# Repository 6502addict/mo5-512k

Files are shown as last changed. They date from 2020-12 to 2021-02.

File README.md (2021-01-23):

# mo5-512k
MO5 512K Cartridge
<br>
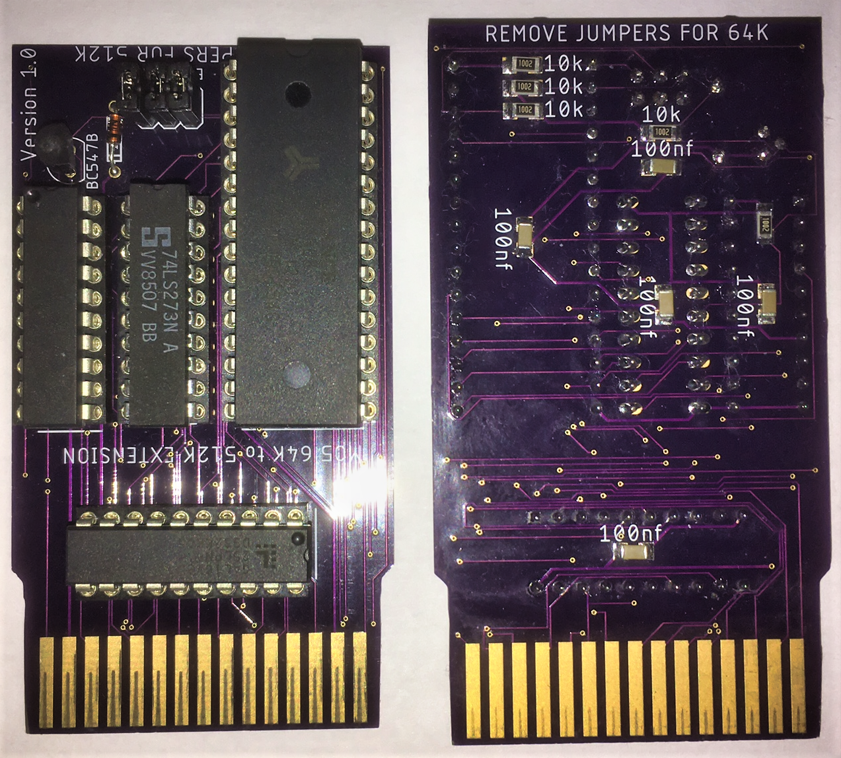
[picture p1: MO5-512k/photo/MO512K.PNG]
al-tag

<br>
## Description
this cartridge is compatible with thomson MO5 64k cartridge
it's not a exact copy of the original cartridge<br>
but rather a rebuild from the manual
<br>
the $A7CB register controlling a MO5 64 cartrige is extended
to permit the access to 512k of memory
<br>
without the 3 jumpers the cartridge is behaving as the 
original thomson MEMO5 cartridge
<br>
with the jumpers set the cartridge can address 512k or memory
<br>

## Note:
The first goal of this board was to replace the original thomson board of 64K
<br>
with the use of modern chips it is easier to find a 128k or 512k chip than 64k
<br>
so I designed the 64k compatibility as the main feature and the extension
<br>
to 128k or 512k (dépending on the ram chip used AS6C1008 or AS6C4008) as goody.
<br>
Due to negative comment on forums saying that this extra memory is useless
<br>
I've listened this comments and removed the jumpers permitting to exploit
<br>
the extra memory.
<br>
As a few 512k board exist I let 512k test procedure and manual
but eagle files are now for 64k boards

## Control Register in $A7CB (without jumpers)
```
bits 0-1   bank number
bit 2      1 = ram visible
           0 = basic
bit 3      1 cartridge ram is readable and writable
           0  cartridge ram is readable and read only
bits 4-7   unused        
```

## Control Register in $A7CB (with jumpers)
```
bits 0-1   bank number
bit 2      1 = ram visible
           0 = basic
bit 3      1 cartridge ram is readable and writable
           0  cartridge ram is readable and read only
bit 4-6    extend the bank number
bit 7      unused
```

## PCB
the pcb can be ordered from oshpark<br>
https://oshpark.com/shared_projects/e0GleW5L

## Bill of Materials
* 1 x socket  dip 32  600mil
* 3 x sockets dip 20  300mil
* 1 74LS273
* 1 RAM Alliance AS6C4008
* 2 GAL Lattice 16v8D
* 1 diode 1N4148
* 5 resistor 10k    1206
* 5 capacitor 100nf 1206
* 1 block of 3 jumpers

## GAL programming
the GALS can be easily programmed with a TL866-II plus programmer<br>
GAL-16V8D-AC7B is going in the horizontal socket  (check the marking)<br>
GAL-16V8D-MO512K is going in the vertical socket

## GAL compiling
The .JED files are sufficent to build the board<br>
they can be recompiled from the .VHD by using:<br>
"Lattice ispLEVER Classic"

## Build of the board
the easiest is to solder the component in the following order<br>
1. 5 100nf capacitor (back of the board)<br>
2. 5 10k resistor (back of the board)<br>
3. 4 sockets<br
4. BC547B<br>
5. 1N4148<br>
6. jumpers<br>

## Test programs
the test program is on Daniel's web site:  http://dcmoto.free.fr/programmes/test512k-mo5/index.html

## Test procedure
follow the instructions in https://github.com/6502addict/mo5-512k/blob/main/MO5-512k/debug

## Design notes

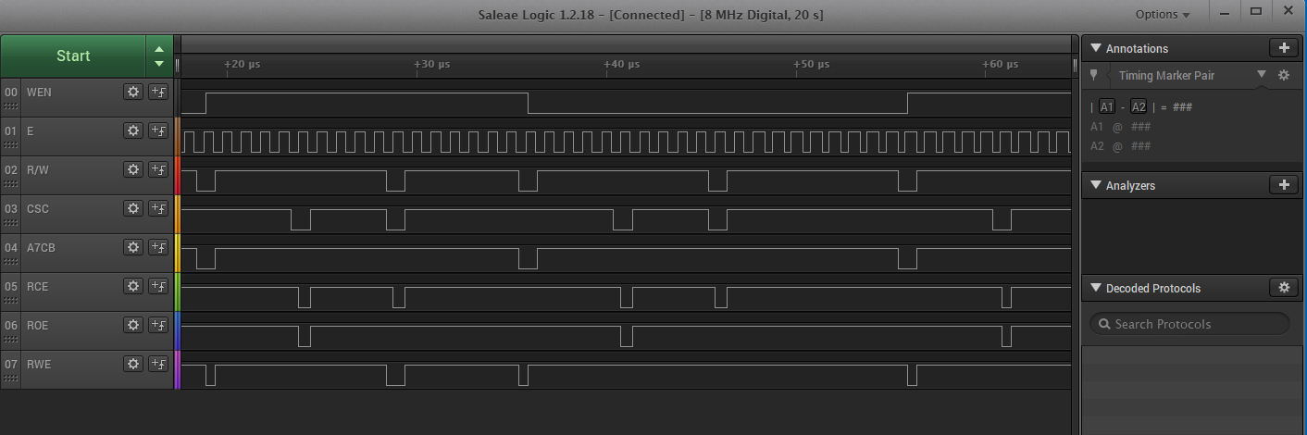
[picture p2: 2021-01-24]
MO5-512k/RAMCTRL.PNG

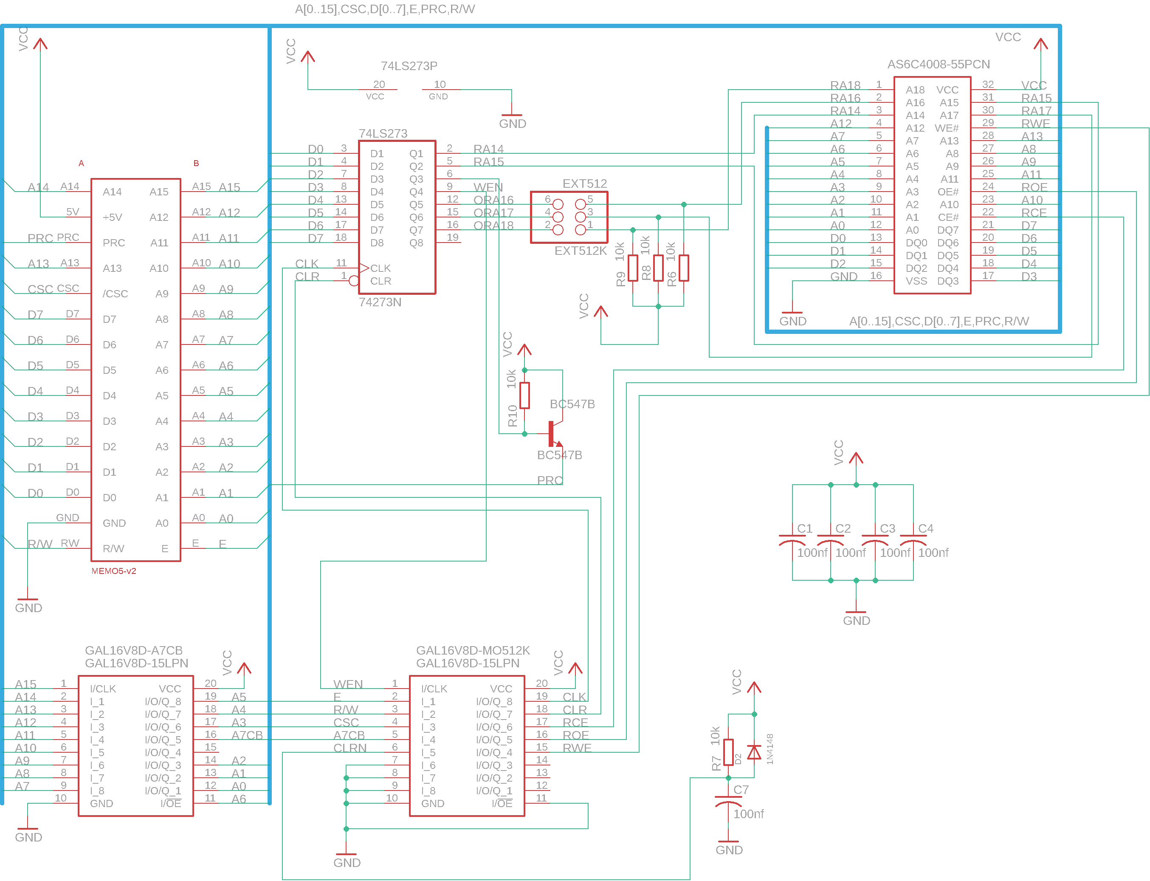
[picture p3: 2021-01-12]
MO5-512k/pcb/mo512k-sch.png

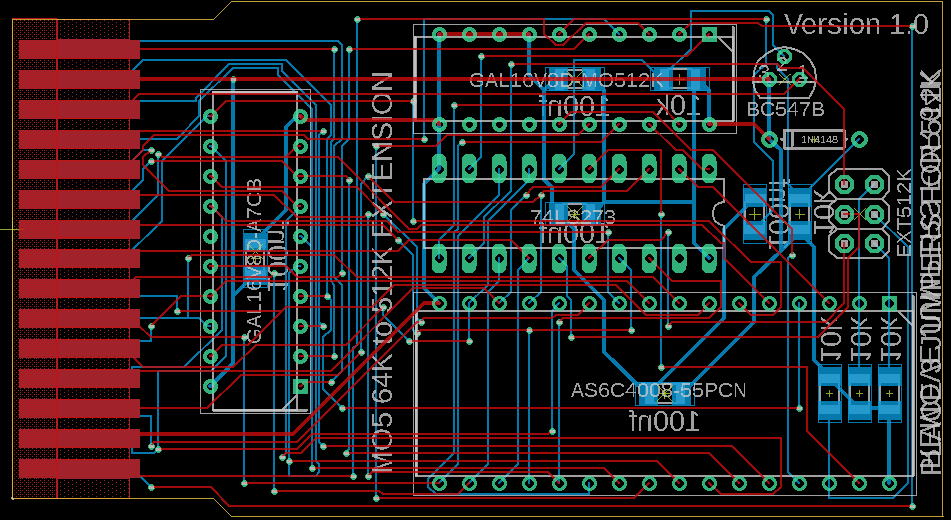
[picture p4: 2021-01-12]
MO5-512k/pcb/mo512k-brd.png

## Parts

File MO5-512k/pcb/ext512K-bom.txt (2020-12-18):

Partlist exported from D:/didier/Documents/EAGLE/projects/perso/mo5/512K/ext512K.sch at 17/12/2020 21:44

Qty Value          Device         Package                     Parts                          Description                   
5   100nf          C-USC1206      C1206                       C1, C2, C3, C4, C7             CAPACITOR, American symbol    
5   10k            R-EU_R1206     R1206                       R6, R7, R8, R9, R10            RESISTOR, European symbol     
1   1N4148         DIODEDO-1N4148 DO-1N4148                   D2                             Diode                         
1   74273N         74273N         DIL20                       74LS273                        Octal D type FLIP FLOP, clear 
1   AS6C4008-55PCN AS6C4008-55PCN DIP1524W58P254L4191H406Q32N AS6C4008-55PCN                 CMOS SRAM                     
1   BC547B         BC547B         TO92                        BC547B                         NPN Transistor                
1   EXT512         PINHD-2X3      2X03                        EXT512K                        PIN HEADER                    
2   GAL16V8D-15LPN GAL16V8D-15LPN DIP762W56P254L2591H533Q20N  GAL16V8D-A7CB, GAL16V8D-MO512K IC CPLD 8MC 15NS 20DIP        
1   MEMO5-V2BRD    MEMO5-V2BRD    MEMO5-BOARD                 U$1

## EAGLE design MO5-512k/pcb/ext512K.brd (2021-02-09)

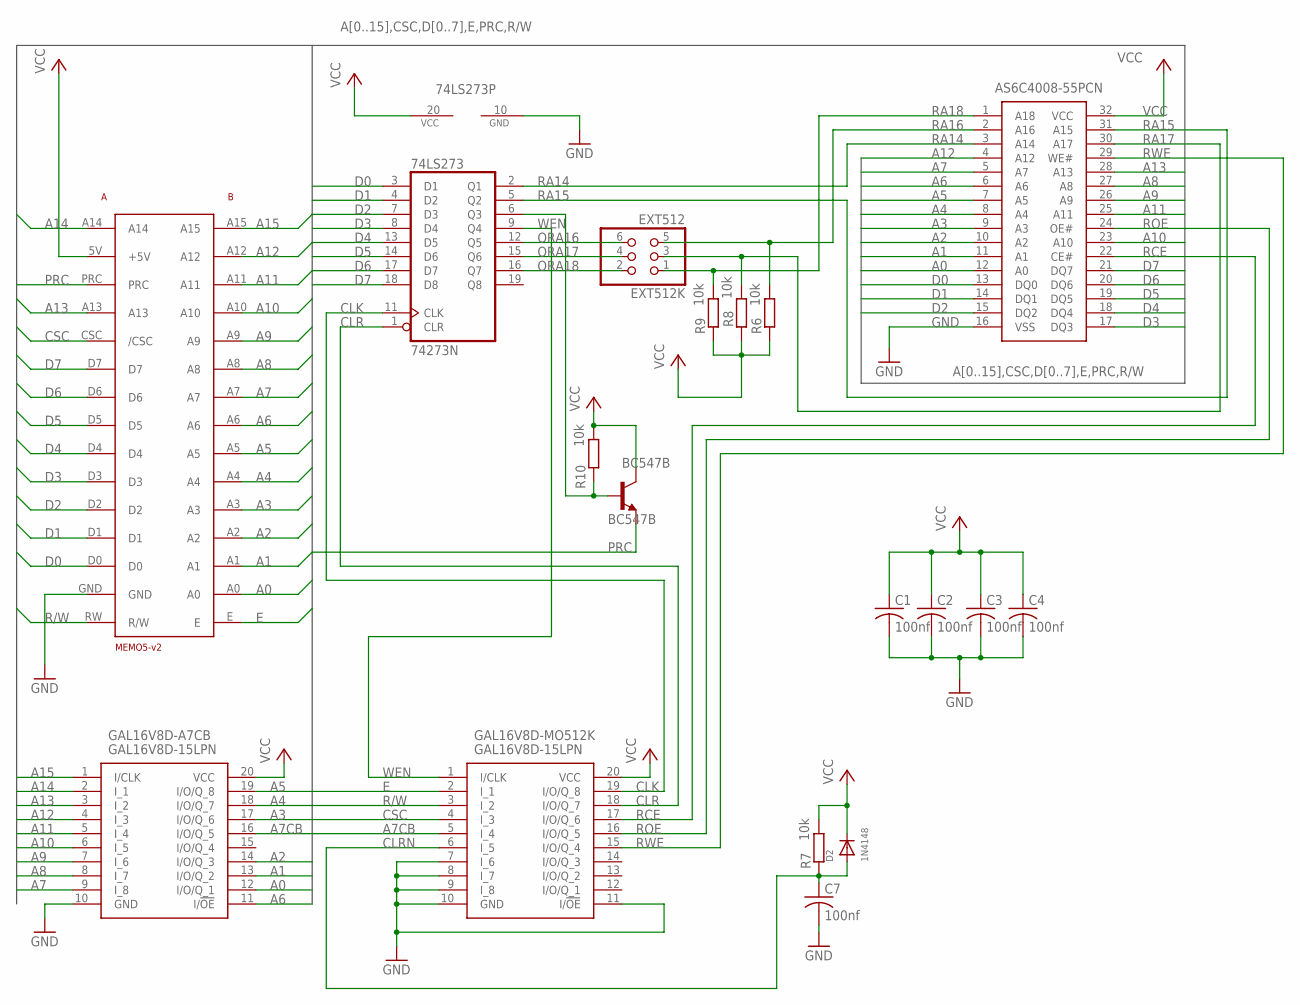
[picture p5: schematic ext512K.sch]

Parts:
74LS273: 74273N; DIL20
AS6C4008-55PCN: AS6C4008-55PCN; DIP1524W58P254L4191H406Q32N
BC547B: BC547B; TO92
C1, C2, C3, C4, C7: 100nf; C1206
D2: 1N4148; DO-1N4148
EXT512K: EXT512; 2X03
GAL16V8D-A7CB, GAL16V8D-MO512K: GAL16V8D-15LPN; DIP762W56P254L2591H533Q20N
R6, R7, R8, R9, R10: 10k; R1206
U$1: MEMO5-V2BRD; MEMO5-BOARD

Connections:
A0: AS6C4008-55PCN.12 (A0), GAL16V8D-A7CB.12 (I/O/Q_1), U$1.A0
A1: AS6C4008-55PCN.11 (A1), GAL16V8D-A7CB.13 (I/O/Q_2), U$1.A1
A2: AS6C4008-55PCN.10 (A2), GAL16V8D-A7CB.14 (I/O/Q_3), U$1.A2
A3: AS6C4008-55PCN.9 (A3), GAL16V8D-A7CB.17 (I/O/Q_6), U$1.A3
A4: AS6C4008-55PCN.8 (A4), GAL16V8D-A7CB.18 (I/O/Q_7), U$1.A4
A5: AS6C4008-55PCN.7 (A5), GAL16V8D-A7CB.19 (I/O/Q_8), U$1.A5
A6: AS6C4008-55PCN.6 (A6), GAL16V8D-A7CB.11 (I/!OE), U$1.A6
A7: AS6C4008-55PCN.5 (A7), GAL16V8D-A7CB.9 (I_8), U$1.A7
A7CB: GAL16V8D-A7CB.16 (I/O/Q_5), GAL16V8D-MO512K.5 (I_4)
A8: AS6C4008-55PCN.27 (A8), GAL16V8D-A7CB.8 (I_7), U$1.A8
A9: AS6C4008-55PCN.26 (A9), GAL16V8D-A7CB.7 (I_6), U$1.A9
A10: AS6C4008-55PCN.23 (A10), GAL16V8D-A7CB.6 (I_5), U$1.A10
A11: AS6C4008-55PCN.25 (A11), GAL16V8D-A7CB.5 (I_4), U$1.A11
A12: AS6C4008-55PCN.4 (A12), GAL16V8D-A7CB.4 (I_3), U$1.A12
A13: AS6C4008-55PCN.28 (A13), GAL16V8D-A7CB.3 (I_2), U$1.A13
A14: GAL16V8D-A7CB.2 (I_1), U$1.A14
A15: GAL16V8D-A7CB.1 (I/CLK), U$1.A15
CLK: 74LS273.11 (CLK), GAL16V8D-MO512K.19 (I/O/Q_8)
CLR: 74LS273.1 (CLR), GAL16V8D-MO512K.18 (I/O/Q_7)
CLRN: C7.1, D2.A, GAL16V8D-MO512K.6 (I_5), R7.1
CSC: GAL16V8D-MO512K.4 (I_3), U$1.CSC (/CSC)
D0: 74LS273.3 (D1), AS6C4008-55PCN.13 (DQ0), U$1.D0
D1: 74LS273.4 (D2), AS6C4008-55PCN.14 (DQ1), U$1.D1
D2: 74LS273.7 (D3), AS6C4008-55PCN.15 (DQ2), U$1.D2
D3: 74LS273.8 (D4), AS6C4008-55PCN.17 (DQ3), U$1.D3
D4: 74LS273.13 (D5), AS6C4008-55PCN.18 (DQ4), U$1.D4
D5: 74LS273.14 (D6), AS6C4008-55PCN.19 (DQ5), U$1.D5
D6: 74LS273.17 (D7), AS6C4008-55PCN.20 (DQ6), U$1.D6
D7: 74LS273.18 (D8), AS6C4008-55PCN.21 (DQ7), U$1.D7
E: GAL16V8D-MO512K.2 (I_1), U$1.E
GND: 74LS273.10 (GND), AS6C4008-55PCN.16 (VSS), C1.2, C2.2, C3.2, C4.2, C7.2, GAL16V8D-A7CB.10 (GND), GAL16V8D-MO512K.7 (I_6), GAL16V8D-MO512K.8 (I_7), GAL16V8D-MO512K.9 (I_8), GAL16V8D-MO512K.10 (GND), GAL16V8D-MO512K.11 (I/!OE), U$1.GND
unnamed: 74LS273.6 (Q3), BC547B.2 (B), R10.1
ORA16: 74LS273.12 (Q5), EXT512K.6
ORA17: 74LS273.15 (Q6), EXT512K.4
ORA18: 74LS273.16 (Q7), EXT512K.2
PRC: BC547B.1 (E), U$1.PRC
R/W: GAL16V8D-MO512K.3 (I_2), U$1.RW (R/W)
RA14: 74LS273.2 (Q1), AS6C4008-55PCN.3 (A14)
RA15: 74LS273.5 (Q2), AS6C4008-55PCN.31 (A15)
RA16: AS6C4008-55PCN.2 (A16), EXT512K.5, R6.2
RA17: AS6C4008-55PCN.30 (A17), EXT512K.3, R8.2
RA18: AS6C4008-55PCN.1 (A18), EXT512K.1, R9.2
RCE: AS6C4008-55PCN.22 (CE#), GAL16V8D-MO512K.17 (I/O/Q_6)
ROE: AS6C4008-55PCN.24 (OE#), GAL16V8D-MO512K.16 (I/O/Q_5)
RWE: AS6C4008-55PCN.29 (WE#), GAL16V8D-MO512K.15 (I/O/Q_4)
VCC: 74LS273.20 (VCC), AS6C4008-55PCN.32 (VCC), BC547B.3 (C), C1.1, C2.1, C3.1, C4.1, D2.C, GAL16V8D-A7CB.20 (VCC), GAL16V8D-MO512K.20 (VCC), R6.1, R7.2, R8.1, R9.1, R10.2, U$1.5V (+5V)
WEN: 74LS273.9 (Q4), GAL16V8D-MO512K.1 (I/CLK)

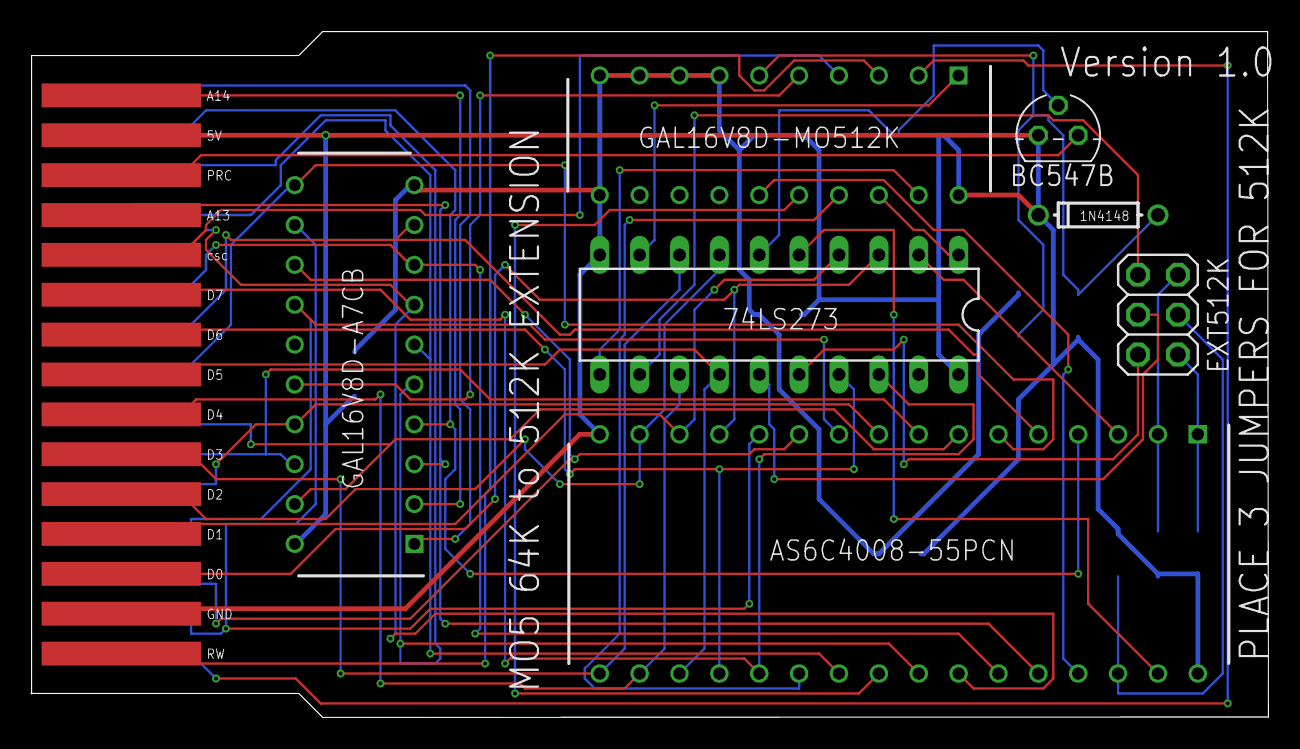
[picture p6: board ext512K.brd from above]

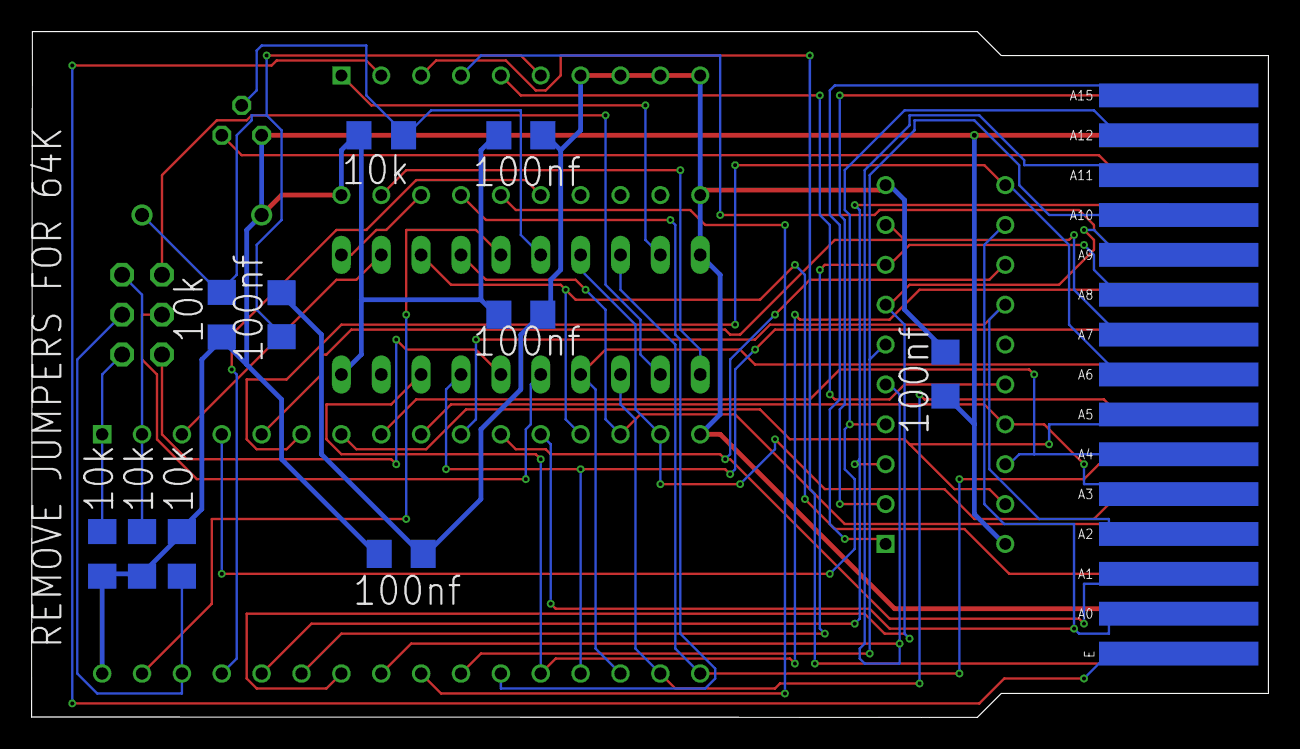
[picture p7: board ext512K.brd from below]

Board: 2 copper layers, 78.8 x 43.7 mm, 18 parts (10 on the bottom side), 47 nets.

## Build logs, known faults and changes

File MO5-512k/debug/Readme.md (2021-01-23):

# MO5 512k Cartridge Debug Procedure
<br>
## Description
If the cartridge is not working, with Daniel's tests
<br>
http://dcmoto.free.fr/programmes/test512k-mo5/index.html
<br>
we will check step by step  the components of the board.

## Tools
We will do that with 2 tools
1/  a TL866 II plus programmer
2/  a 8 channels logic analyser  (around 10€ on amazon)

# Component Check

## Check the 74LS273
Select "logic test" on the programmer and clic on "autofind"
<br>
the programmer should detect a "74273"

## Check the RAM chip
Select device "SRAM/VRAM" then select "Standard RAM"
<br>
and choose 628512 and press "select"
<br>
then in the new windows click on "TEST"
<br>

## Check the GAL16V8D-A7CB
the GAL16V8D-A7CB (horizontal) produce a chip select when the latch 74LS273 is accessed
as it is not possible to connect the analyser directly on this GAL
we will test it on the entry of this signal on the GAL16V8D-MO512K (vertical)

Connections to realise between the logic analyser and the GAL
- GND to pin 10   "GND"
- CH1 to pin 5    "A7CB"     

Program to run
Start he MO5 and select "test512k.sd" in sddrive menu
<br>
in the basic load  "A7CB"
<br>
run the basic program
<br>
<br>
Capture the data with the analyser
<br>
with the following settings:
<br>
https://github.com/6502addict/mo5-512k/blob/main/MO5-512k/debug/setup-A7CB.logicsettings
<br>
you should get the following pattern
<br>
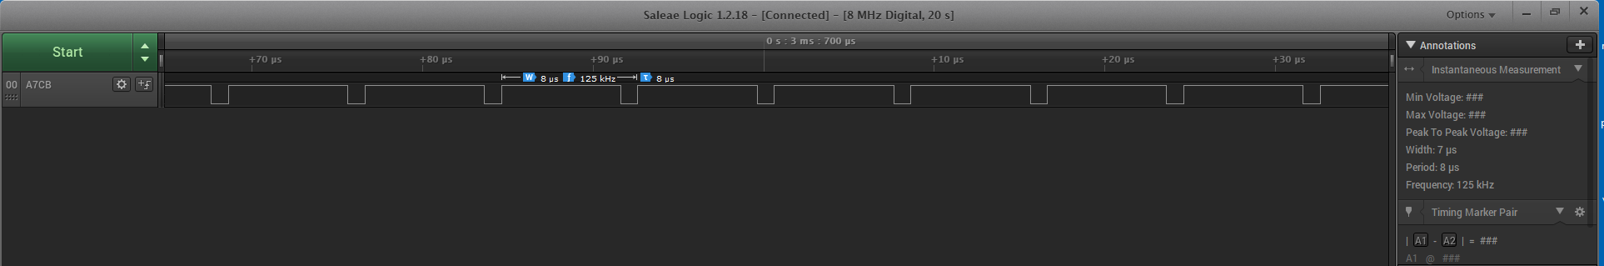
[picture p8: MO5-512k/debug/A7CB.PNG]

<br>
if the you have not a similar probleme check the following signals:
- the address lines from the MO5 connector to the GAL-A7CB pins
- check the solders of the GAL chip
- eventually program another GAL with GAL16V8D-A7CB.jed

## Check the GAL16V8D-MO512k latch control signals
the GAL 16V8D-MO512K controls 3 functions
- the generation of CLR and CLK signals for the 74LS273
- the generation of the control signals for the ram chip

Connections to realise between the logic analyser and the GAL
- GND to pin 10    "GND"
- CH1 to pin  2    "E" 
- CH2 to pin  3    "R/W"
- CH3 to pin  5    "A7CB"
- CH4 to pin 19    "CLK" 

Program to run
Start he MO5 and select "test512k.sd" in sddrive menu
<br>
in the basic load  "CLK"
<br>
run the basic program
<br>
<br>
Capture the data with the analyser
<br>
with the following settings:
<br>
https://github.com/6502addict/mo5-512k/blob/main/MO5-512k/debug/setup-CLK.logicsettings
<br>
you should get the following pattern
<br>
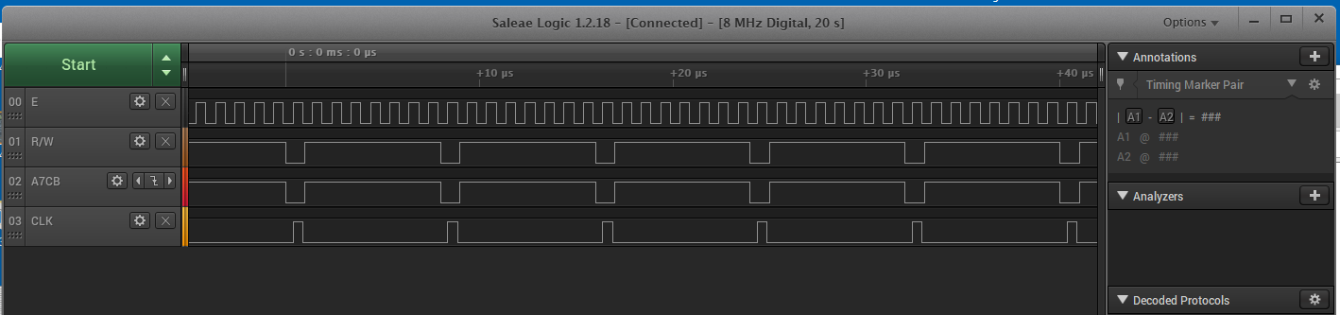
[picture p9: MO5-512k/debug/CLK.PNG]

<br>
if the you have not a similar probleme check the following signals:
- the lines: E, A7CB and R/W
- check the solders of the GAL chip
- eventually program another GAL with GAL16V8D-MO512K.jed

## Check the 74LS273 functions
the 74LS273 select the active bank as well as the cartridge/basic acces
and protect from the write to the ram chip

Connections to realise between the logic analyser and the GAL
- GND to pin 10    "GND"
- CH1 to pin 11    "CLK" 
- CH2 to pin  2    "BANK0"
- CH3 to pin  5    "BANK1"
- CH4 to pin  6    "BASIC/CART" 
- CH5 to pin  9    "WEN" 
- CH6 to pin  12   "BANK2" 
- CH7 to pin  15   "BANK3" 
- CH7 to pin  16   "BANK4" 

Program to run
Start he MO5 and select "test512k.sd" in sddrive menu
<br>
in the basic load  "74LS273"
<br>
run the basic program
<br>
<br>
Capture the data with the analyser
<br>
with the following settings:
<br>
https://github.com/6502addict/mo5-512k/blob/main/MO5-512k/debug/setup-74LS273.logicsettings
<br>
you should get the following pattern
<br>
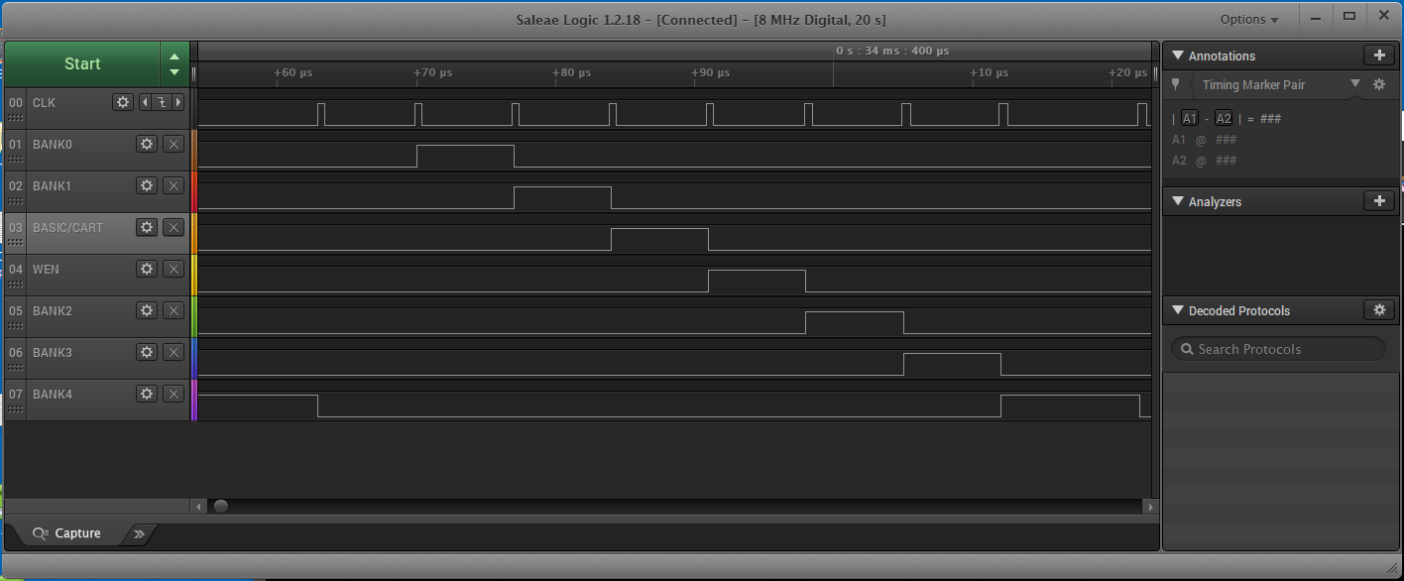
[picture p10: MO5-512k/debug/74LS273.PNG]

<br>
if the you have not a similar probleme check the following signals:
- the lines: D0 to D7, CLK and CLR
- check the solders of the GAL chip

## Check the GAL16V8D-MO512K RAM control signals
the GAL GAL16V8D-MO512K also control the control signals for the ram chip

Connections to realise between the logic analyser and the GAL
- GND to pin 10    "GND"
- CH1 to pin  1    "WEN" 
- CH2 to pin  2    "E"
- CH3 to pin  3    "R/W"
- CH4 to pin  4    "CSC" 
- CH5 to pin  5    "A7CB 
- CH6 to pin  17   "RCE" 
- CH7 to pin  16   "ROE" 
- CH7 to pin  15   "RWE" 

Program to run
Start he MO5 and select "test512k.sd" in sddrive menu
<br>
in the basic load  "RAMCTRL"
<br>
run the basic program
<br>
<br>
Capture the data with the analyser
<br>
with the following settings:
<br>
https://github.com/6502addict/mo5-512k/blob/main/MO5-512k/debug/setup-RAMCTRL.logicsettings
<br>
you should get the following pattern
<br>
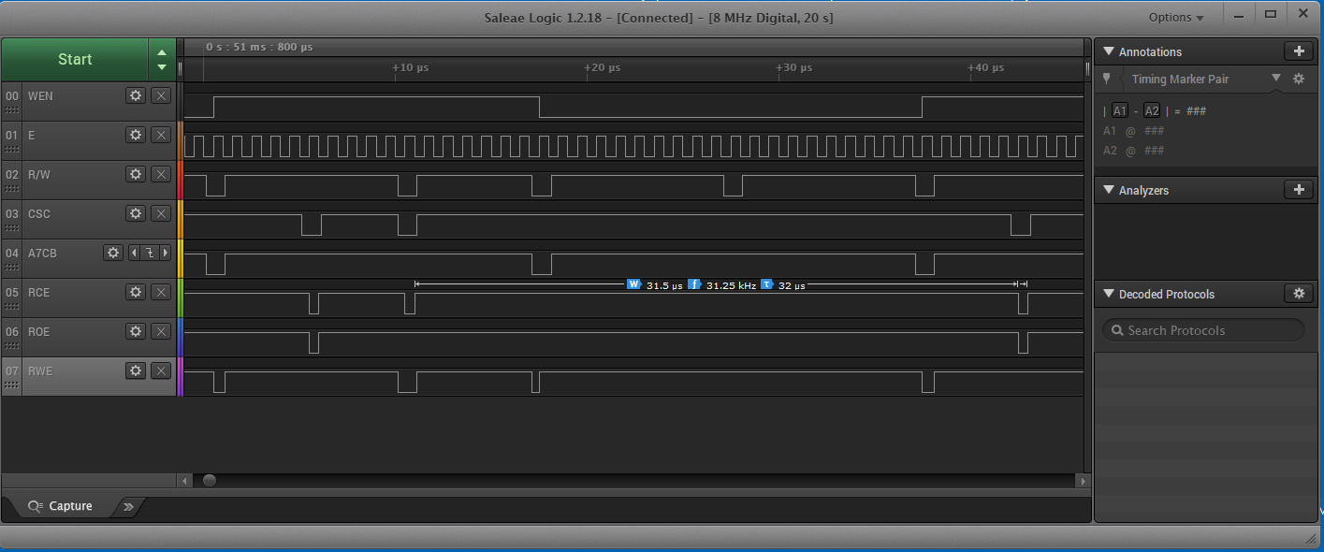
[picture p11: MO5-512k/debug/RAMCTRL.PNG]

<br>
This one needs a bit more explanations
<br>
there are 2 phases
- in the first phase wen is set to 1 and a read and a write occurs
- in the second phase wen is set to 0 and a read occurs but a write is blocked (no signal on RWE)
<br>
if the you have not a similar probleme check the following signals:
- the lines: WEN, E, R/W, CSC, A7CB
- check the solders of the GAL chip

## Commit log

2021-01-12 Add files via upload
    Slightly modified the bottom silk for a missing component value
    added the schematics and pcb in png format
    [ext512K.brd]
2021-01-12 Add files via upload
    Added a photo of the board
2021-01-23 Update README.md
    completed the test procedure
    updated oshpark link to 64k board
